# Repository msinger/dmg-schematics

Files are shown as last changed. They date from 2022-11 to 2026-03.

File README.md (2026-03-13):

Game Boy DMG-CPU Schematics
===========================

Contains reverse engineered schematics of the Game Boy DMG-CPU B chip, including the SM83 CPU core, as well as
VLSI layouts and parsable netlists.

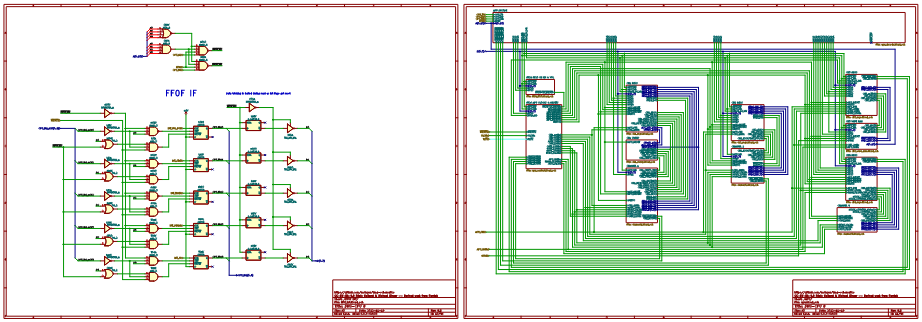
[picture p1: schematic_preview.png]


Originally, the DMG-CPU B schematics in this repository were derived from the schematics in
[furrtek/DMG-CPU-Inside](https://github.com/furrtek/DMG-CPU-Inside) (CC-BY-SA 4.0 Furrtek). They contain a lot of fixes
that were never applied to DMG-CPU-Inside.

PDF Export
----------

Most recent PDF exports can be found in the
[release](https://github.com/msinger/dmg-schematics/releases) section on github.

Files in this repo
------------------

| File(s) | Description |
| --- | --- |
| ./dmg\_cpu\_b/\* | KiCad project with schematics of the DMG-CPU B chip. |
| ./sm83/\* | KiCad project with schematics of the SM83 CPU core. |
| ./dmg\_cpu\_b/overlay/dmg-cpu-b\_overlay.svg | Modified version of Furrtek's overlay for the chip's die shot. |
| ./dmg\_cells/dmg-cpu.jelib | Electric VLSI cell library containing layouts of the standard cells used in the chip. |
| ./sm83\_cells/sm83.jelib | Electric VLSI cell library containing the layout of the complete SM83 CPU core. |
| ./netlist/\* | Text files containing all cells and wires, and their connections and coordinates. |

Overlay SVG
-----------

The overlay SVG image contains the contours of the cells in the die shot and highlights all the wires
connecting the cells. Also, the cells are labeled with the same names they have in the schematics.

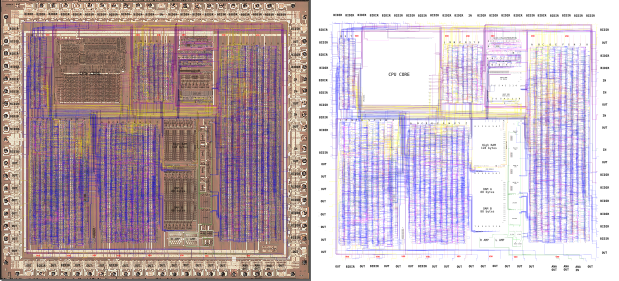
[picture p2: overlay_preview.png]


We took the overlay from Furrtek and modified it to keep it in sync with the fixed schematics.

To open the overlay with an SVG viewer/editor (like Inkscape) you need to download the die shots and place
them into the same directory where the overlay file is.
The die shots (`nintendo_dmg-cpu-b_mcmaster_mz_mit20x.jpg` and `nintendo_dmg-cpu-b_mcmaster_s1-1_mit20x.jpg`)
can be downloaded from [here](https://siliconpr0n.org/map/nintendo/dmg-cpu-b/single/).

Electric VLSI Library
---------------------

The [Electric VLSI](https://www.staticfreesoft.com/) libraries contain layouts for the standard cells used
in the chip as well as the complete SM83 CPU core.

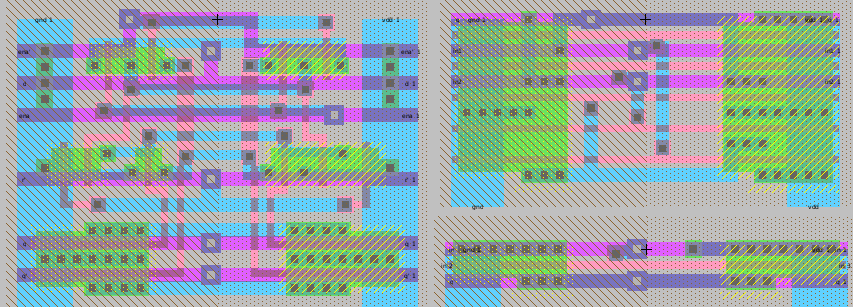
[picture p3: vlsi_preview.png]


Screenshots of these layouts can be seen in the cell reference documentations:
[dmg\_cells](http://iceboy.a-singer.de/doc/dmg_cells.html),
[sm83\_cells](http://iceboy.a-singer.de/doc/sm83_cells.html)

Netlist
-------

The files in the netlist folder contain definitions for all cells and wires of the chip.
They can be parsed by the [nlconv](https://github.com/msinger/nlconv/) tool. This tool is
currently capable of converting the netlists into the following products:
 * HTML file with colors and links that make the netlists more readable.
 * PNG images that are used for the overlays on the Leaflet maps of the chip:
   [dmg\_cpu\_b\_map](http://iceboy.a-singer.de/dmg_cpu_b_map/) and
   [sm83\_map](http://iceboy.a-singer.de/sm83_map/).
 * JavaScript code that is used by the same Leaflet maps for allowing the user to click on and select cells and wires,
   to get more information about them.
 * SystemVerilog code for simulating the chip: [dmg-sim](https://github.com/msinger/dmg-sim/)

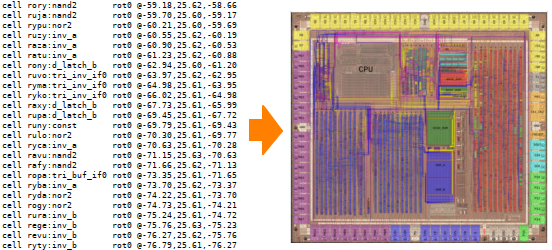
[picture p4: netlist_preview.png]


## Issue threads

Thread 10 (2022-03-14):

JOY: SIN IO-pad pull-up enable is wrong

msinger, 2022-03-14:
On joypad sheet, the pull-up enable input of the SIN IO-pad should be connected to net FF60_D0, not GND. This is also wrong in Furrtek's schematic.

Closed 2022-03-16.

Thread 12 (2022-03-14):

CLOCK: AGUT pins swapped

msinger, 2022-03-14:
On clock sheet, inputs 1&2 of AGUT are swapped. Makes no difference though, since both are inputs to or gate part of this OA cell. Also wrong in Furrtek's schematic.

Closed 2022-03-16.

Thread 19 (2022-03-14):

JOY: Block with AXYN, ADYR, ... belongs to another sheet

msinger, 2022-03-14:
The block in the top right corner of the joypad sheet should be moved to another sheet. I'm not sure where it fits best however. Maybe CPU sheet. The comment is wrong. This block is used for pre-charging the data bus at the beginning of each memory cycle. It causes non-existent bits in address range 0xFE00-0xFFFF to always be read as 0xFF.

There is also a bug that got transferred over from Furrtek's schematics: The signal FROM_CPU is wrong. This should be T1~{T2}.

Closed 2022-03-16.

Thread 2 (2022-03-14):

INT: Replace PESU with VCC

msinger, 2022-03-14:
On the interrupt sheet, PESU should be replaced with direct connection to VCC.

Closed 2022-03-16.

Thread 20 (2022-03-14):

DMA: Inputs of LAVY are swapped

msinger, 2022-03-14:
On DMA sheet, the inputs of AND gate LAVY are swapped.

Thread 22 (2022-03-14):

DMA: Input 1 of LYXE is wrong

msinger, 2022-03-14:
On DMA sheet, input 1 of LYXE (see also #21) is wrongly connected to LORU. It should be connected to LAVY instead. This bug got carried over from Furrtek's schematic.

Closed 2022-03-16.

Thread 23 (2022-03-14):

DMA: Latch enable inputs are inverted

msinger, 2022-03-14:
The D_LATCH_A enable inputs on the DMA sheet all need to be inverted.

Closed 2022-03-16.

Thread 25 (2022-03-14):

DMA: Input 2 of NAXY is wrong

msinger, 2022-03-14:
On DMA sheet, input 2 of NAXY is wrongly connected to Q output of LUVY. It should be connected to the CLK input of LUVY, which is DMA_PHI. This was also wrong in Furrtek's schematics.

Closed 2022-03-16.

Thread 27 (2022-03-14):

SER: SCK IO-pad is not connected correctly

msinger, 2022-03-14:
On serial sheet, the SCK IO pad is not correctly connected:

* First, it should be IOBUF_C, not _B. SCK is the only IO of that type. I don't know what's the difference, though,
* DRV_LOW and DRV_HIGH inputs are swapped. NOR gate KUJO should be connected to the NMOS driver (DRV_LOW) and NAND gate KEXU should be connected to the PMOS driver (DRV_HIGH).
* The pull-up resistor should be enabled by signal SCK_DIR, instead of GND.

rgalland, 2022-03-16:
Well done for working this one out.

Closed 2022-03-16.

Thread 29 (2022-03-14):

SYS_DEC: Reset input pad should be labeled ~RESET

msinger, 2022-03-14:
On the SYS_DECODE sheet, the reset input pad should be labeled with a bar on top, because the reset pin is active low.

On page 19 of [Nintendo's Game Boy Programming Manual](http://index-of.es/Varios-2/Game%20Boy%20Programming%20Manual.pdf) this pin is labeled ~RESET. Also in the [1996 Sharp Microcontroller Data Book](https://archive.org/details/1996_Sharp_Microcomputer_Data_Book/page/n147/mode/2up) on page 148 of the PDF (141 is written on the page itself), the SM83xx family has the reset pin labeled ~RESET.

There are other non official sources that label it ~RST, like in [Jeff Frohwein's GameBoy Schematic](https://www.devrs.com/gb/files/gameboy1.gif), but I think we should go with the official writing style.

Closed 2022-03-16.

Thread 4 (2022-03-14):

JOY: P10_IN, ..., P13_IN are inverted

msinger, 2022-03-14:
On joypad sheet, the signals P10_IN, P11_IN, P12_IN and P13_IN should have a bar on top, because they are inverted.

msinger, 2022-03-16:
No we can't label the pins active low like ~P10. They are not labeled active low in any documents and this would contradict how they are used in software:
Reading bit 0-3 in FF00 yields the non-inverted state of inputs P10-P13. And writing bits 4-5 to 0 causes outputs P14&P15 to be driven to GND. So they shouldn't be labeled as active low.

But since the input buffer of all IO pads are inverting, the internal signal P10_IN should be ~P10_IN instead to reflect that inversion.

Closed 2022-03-16.

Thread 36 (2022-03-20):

EXT_ADDR: Label ~EXT_ADDR_EN placed wrong

msinger, 2022-03-20:
On EXT_ADDR_BUSES sheet, the label ~EXT_ADDR_EN, which was NET01 in Furrtek's schematics, should come from TOVA, not RYCA.

msinger, 2022-03-20:
Also, there should be no connection between SYZU and NEFE. SYZU gets its enable input from RYCA. NEFU and the others get it from TOVA.

Closed 2022-03-20.

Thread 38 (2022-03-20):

EXT_ADDR: Many wrong DMA_A0 labels

msinger, 2022-03-20:
On EXT_ADDR_BUSES sheet, there are many MUX select inputs labeled DMA_A0, which should have another index other than 0.

rgalland, 2022-03-20:
Oops, A bit tired here.

Closed 2022-03-20.

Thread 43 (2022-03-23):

DUCE conencted to FERY

rgalland, 2022-03-23:
Hi @msinger, can you understand why FERY is not connected to FF18?

msinger, 2022-03-23:
Yes, I can. In Furrtek's schematics there is a connection, because it's hard to follow the wires here on the die shot. He just didn't see it correctly. Took me a long time too, to find this. I made two images in issue furrtek/DMG-CPU-Inside#62 already, that illustrate the problem.

msinger, 2022-03-23:
So, this means you can also remove the outgoing hierarchical label DUCE on the APU decode sheet, I think.

Closed 2022-03-24.

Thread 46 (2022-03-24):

APU_DEC: Inputs of some gates are swapped

msinger, 2022-03-24:
On APU decode sheet, the inputs of following gates are swapped:
DYVA, CAXE, EDAF, DECO, DUJA, COVY, DUTU, DARA, DOZA, EMOR, EKEZ

I compared it with the die shot. Furrtek also made a few mistakes here.

msinger, 2022-03-24:
Just noticed, the inputs of the NAND_4 gates are also scrambled up. I say we leave them like that for now. :)

rgalland, 2022-03-24:
I'll leave a note on the schematics about the NAND inputs.

Closed 2022-03-24.

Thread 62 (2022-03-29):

APU CH2: Swapped inputs

msinger, 2022-03-29:
On APU CH2 sheet, inputs of GUFY are swapped.

Btw., you left something copy&pasted from CH1 below this sheet (out of bounds). Probably used it for comparing the similar circuits.

Closed 2022-03-29.

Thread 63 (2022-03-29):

APU CH3 REGS: Missing FEVO and wrong connections to GUXE

msinger, 2022-03-29:
On APU CH3 register sheet, FEVO is missing. Also there are wrong connections carried over from Furrtek.

* Q output of GUXE should be connected to FEVO's input and nowhere else. Then output of FEVO goes into GEKO, like it is drawn in Furrtek's schematics.
* ~Q output of GUXE should go into FUVO input 1. The label ~CH3_AMP_EN (aka. ~FF1A_D7) should stay at the ~Q output.

msinger, 2022-03-29:
Also look at #64 before making changes. It's in the same area.

rgalland, 2022-03-29:
Also fixed BUTA on CH2 as output was not connected to ~Q. I also renamed all labels to CHx_FDIS instead of CHx_FEN as it makes more sense.

Closed 2022-03-29.

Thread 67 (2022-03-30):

APU CH4 REGS: ~FF23_D6 label is missing

msinger, 2022-03-30:
On APU channel 4 register sheet, the label ~FF23_D6 is missing on CUNY's ~Q output. In Furrtek's schematic this label is placed at CEPY's output, which is wrong. CEPY only connects to COTE. You have correctly identified DODA input 3 as ~FF23_D6. I wasn't aware of that bug before, thanks.

msinger, 2022-03-30:
Also DYRY shouldn't be connected to CEPY. DYRY input 1 is FF23_D6, not ~FF23_D6. This is wrong in Furrtek's schematic.

Closed 2022-03-31.

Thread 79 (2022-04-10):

PPU STAT: Wrong output of WUSA used

msinger, 2022-04-10:
On PPU STAT sheet, WUSA has the wrong output connected. It should use Q instead of ~Q.

rgalland, 2022-04-10:
Well spotted. I always end up getting it wrong when flipping these latches. In this case, I didn't even need to as WUSA could have sat above XYMU without crossing signals. This will be fixed in next commit.

Closed 2022-04-10.

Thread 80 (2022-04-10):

PPU STAT: FF45 latches are in random order

msinger, 2022-04-10:
On PPU STAT sheet, the latches of register FF45 are in wrong order. They actually have the reversed random order than in Furrtek's schematic. From top to bottom (7 to 0), they should be named:
RAHA
VEVO
VAFA
SOTA
SALO
SEDY
VUCE
SYRY

The tri-states and XORs are in correct order.

Closed 2022-04-10.

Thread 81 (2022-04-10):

Redrawing FULL ADD symbol

rgalland, 2022-04-10:
Do you mind if we draw the FULL ADD symbol to have from top to bottom :
- A, B, CIN on the left
- and COUT and SUM on the right?

This will prevent a lot of lines crossing over. At the moment, only the SWEEP sheet is affected but it look as I always try to have the MSB at the top.

msinger, 2022-04-10:
Let's do it. It's good to have everything ordered the same way. And if changing the pin order is making everything more readable, then that's good to.

Closed 2022-04-10.

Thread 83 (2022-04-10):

PPU LCD: SACU is an OR

msinger, 2022-04-10:
On PPU LCD sheet, SACU should be an OR gate, not a NOR. Is also wrong in Furrtek's schematics.

Closed 2022-04-10.

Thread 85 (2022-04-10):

PPU: Missing file

msinger, 2022-04-10:
Forgot to add background.kicad_sch to repo.

rgalland, 2022-04-10:
It's not ready yet but I can add it in case it messes up the Kicad project on your side.

msinger, 2022-04-11:
Ok, thanks. I thought you may have forgotten it. FYI.: KiCad loads the project and a warning about the missing file pops up, but the other sheets can still be viewed/edited normally.

Closed 2022-04-10.

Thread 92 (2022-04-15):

PPU WIN: ~RESET of RYFA and RENE is not connected

msinger, 2022-04-15:
On PPU window detection sheet, the ~RESET inputs of RYFA and RENE are not connected to any driver. They should be connected to MODE3 (XYMU.~Q).

Closed 2022-04-15.

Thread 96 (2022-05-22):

PPU VRAM_IFC: TEGU input 2 is wrong

msinger, 2022-05-22:
On VRAM interface sheet, input 2 of TEGU should not be connected to WRITE_EN (AFAS). It is connected to WRITE (FROM_CPU3). This is also wrong in Furrtek's schematics: furrtek/DMG-CPU-Inside#48

rgalland, 2022-05-23:
Well done. I thought that didn't make sense.

Closed 2022-05-23.

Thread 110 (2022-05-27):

PPU PX_MUX: Wrong connections between MEXA/LOZO/MABY/LYLE and LEDO/LARU/LYKY/LOPU

msinger, 2022-05-27:
On pixel mux sheet, MEXA should be connected to input 1 of LYKY and LOPU, not LARU. LOZO should be connected to input 1 of LEDO and LARU, not LYKY. MABY should be connected to input 2 of LOPU and LARU, not LYKY. LYLE should be connected to input 2 of LEDO and LYKE, not LARU.

Closed 2022-05-27.

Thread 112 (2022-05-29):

PPU DECODE: BOTA should be NAND

msinger, 2022-05-29:
On PPU decode & video control sheet, BOTA should be a NAND, not a NOR. This is also wrong in Furrtek's schematics.

msinger, 2022-05-29:
Well, I'm confused. The symbol is already NAND, but the label is NOR.

Closed 2022-05-30.

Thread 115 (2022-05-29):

PPU OAM: GND and +5V swapped

msinger, 2022-05-29:
On OAM sheet, WYDU and GECA should be connected to +5V, WUWE and GEFY should be connected to GND.

Closed 2022-05-30.

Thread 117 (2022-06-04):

CPU: Wrong OSC_STABLE input

msinger, 2022-06-04:
On CPU sheet, the OSC_STABLE (T15) input of the CPU is not 16Hz. It is output of TABA.

rgalland, 2022-06-05:
Well spotted.

msinger, 2022-06-05:
You forgot updating the ports of the CPU sheet symbol on the top sheet. 16Hz is still there and RESET_RELEASE is not connected.

Also I hate to nag, but I don't think RESET_RELEASE is a good name. Because for the CPU this not only gets signaled when the reset is released. It also happens after waking up from STOP instruction. STOP instruction causes OSC_ENABLE to swicth off. When the CPU gets the WAKE signal, then it rises OSC_ENABLE again, then TABU again takes some time until it signals stable oscillator back to the CPU. When in STOP mode, the CPU doesn't get reset, otherwise it wouldn't continue running after the STOP instruction. That's why I think RESET_RELEASE doesn't quite fit. Most of the other parts of the chip are reset during STOP mode, so for them it would be true that the reset is released at that point. But this signal goes to the CPU specifically.

rgalland, 2022-06-05:
Yes, I wouldn't mind giving it a more meaningful name but could not come with anything. Did you want to call OSC_STABLE? Is this a name you got from the Z80 documentation? Also do you what the relation is between CLK_ENA and OSC_ENA. It looks like CLK_ENA can only go high when reset stops otherwise TUBO would prevent the 16Hz signal to be seen by ASOL.

msinger, 2022-06-05:
No, I think I came up with OSC_STABLE on my own after experimenting a lot with the simulation. You are correct. The CPU must not pull CLK_ENA high before OSC_STABLE is high. Otherwise some of the reset signals will not go away. I already documented somewhat about this on my page http://iceboy.a-singer.de/doc/dmg_cpu_connections.html in row T11.
I concluded that the CPU has to do the following and implemented that in my simulation:
1. On reset, initially keep CLK_ENA low. OSC_ENA can be high immediately.
2. When OSC_STABLE rises, CPU drives CLK_ENA high. Now CPU starts actually running, because now it has all clocks.

When CPU encounters a STOP instruction it drives OSC_ENA and CLK_ENA low. When WAKE goes high, then it repeats from step 1. (OSC_ENA=high; wait for OSC_STABLE; CLK_ENA=high)

When CPU encounters a HALT instruction it drives CLK_ENA low, but keeps OSC_ENA high of course. Now the rest of the system is still clocked, but the CPU misses most of its clocks and won't continue executing. An interrupt will cause the CPU to drive CLK_ENA high again. It doesn't use WAKE, because WAKE is only for waking up if there is no clock at all. When in HALT the CPU still has some clock.

Yes, I would call it OSC_STABLE.

rgalland, 2022-06-06:
Thank you for the explanation, it makes a lot of sense. I'll have to check my VHDL code but I think that's how I implemented STOP and HALT instructions.
The signal will be renamed in the next commit to OSC_STABLE but I can leave the issue open until then.

Closed 2022-06-08.

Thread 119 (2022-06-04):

PPU DECODE: XECY is DR-latch

msinger, 2022-06-04:
On video decode sheet, XECY is a DR_LATCH, not D_LATCH_A. Its data input comes from D7, not XEBE. But its /RESET input comes from XEBE. Enable input should be WARU, not XUCA. XUCA is connected to its /ENA input, so XUCA is just a COMP CLOCK. This is also wrong in Furrtek's schematic. It is correct that Q output is in use and /Q is NC.

Closed 2022-06-05.

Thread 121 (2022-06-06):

SPRITE Y COMP: TOBU and VONU wrong connections

msinger, 2022-06-06:
On sprite Y comparator sheet, the clock of TOBU and VONU should come from TAVA (CLK5), not CLK4. Also, Q output of TOBU should be used. /Q is NC. Both of this is also wrong in Furrtek's schematic.

Closed 2022-06-08.

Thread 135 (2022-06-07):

Bus labels ending in underscore

msinger, 2022-06-07:
For some reason you added an underscore at the end of most sprite related bus labels (like SAVE_SPRITE_X_[0..9]).
Although, this may look good for the individual wires coming out of those buses (SAVE_SPRITE_X_0), it is inconsistent with other buses (like OAM_PARSE_A[2..7]).
More bothering to me is that when we translate this schematics one-to-one to Verilog or VHDL, we would end up with ugly vector or array names that have this underscore at the end.

rgalland, 2022-06-09:
True, this is a good point.

rgalland, 2022-06-09:
Changed other buses too.

msinger, 2022-06-09:
SPRITE_X_ and SPRITE_ON_ still have _

Closed 2022-06-10.

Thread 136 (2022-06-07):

SPRITE X MATCH TOP: Wrong data input for VEZO

msinger, 2022-06-07:
On sprite X match top sheet, VEZO should get constant +5V into its data input, not GND.

Closed 2022-06-09.

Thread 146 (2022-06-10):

IO pin names

msinger, 2022-06-10:
I would like to have the IO pins labeled the same as they are in the official Programming Manual on page 20: https://archive.org/details/GameBoyProgManVer1.1/page/n19/mode/2up

Right now, some are missing the bar on top (MCS, MWR, MOE). In the manual, MOE is labeled /MRD. This makes it consistent with the cartridge bus. On the PCB of the Game Boy Pocket, the test point on this trace is also labeled MRD. (http://iceboy.a-singer.de/db/mgb_iceboy_1/pcb_front.jpg)
Also in the Game Boy Color Service Manual, the pin names seem to match the ones from the Programming Manual: https://gamesx.com/wiki/lib/exe/fetch.php?media=schematics:gameboy_color_service_manual.pdf

You labeled /CS as /RAM_CS. I think it would make sense to add a comment next to it that says "RAM chip select" and then also next to A15 that says "ROM chip select".

As an exception, I think we should stick with PHI. I don't think it is a good idea to add Greek letters to KiCad.

I don't know how to best name the oscillator IO pins. We can leave it as it is or name it CK1_CK2, or just CK? I haven't figured out which one (CK1 or CK2) is output and which is input. In non-official documentation, they are mostly labeled XI and XO. I might have to measure it on a Game Boy Pocket. They are also labeled on its PCB.

I also think it may be good to have a comment next to each IO pin, that contains the pin number (or numbers in case of OSC).

When we start changing the SVG overlay later, we should not forget to name all the pins the same there.

Maybe we can add IO pads for GND and VDD also.

What do you think?

rgalland, 2022-06-11:
These are all good comments. I'll stat with renaming the pins according to the manual and adding notes as you suggested.

I can only imagine that CK1 is XO and CK2 is XO but I will need to check. In anycase, we can use CK1 and CK2 and add notes again.

Yes, it definitely make sense to have the GND and 5V pins to show that they do come from somewhere.

Let's leave this ticket open for now and perhaps use it to list all of the tasks to be done and then move to individual issues if they are big tasks. The overlay will be a big one.

msinger, 2022-06-11:
@Gekkio drew a pinout of the chip: https://github.com/Gekkio/gb-ctr/blob/master/images/DMG-CPU-pinout.pdf
According to this, pin 74 is CK1. I know from my experiments that pin 74 is the clock input and pin 73 is the output.
This means CK1 is XI and CK2 is XO. I don't know what you guessed in your comment, because you accidentally wrote XO twice. :grin:

What I also found while looking through his stuff, you can put nets with different names on one single bus now in KiCad, like he did here: https://github.com/Gekkio/gb-schematics/blob/main/MGB-xCPU/schematic/MGB-xCPU.pdf

rgalland, 2022-07-02:
I'm about o commit changes. Can you please check naming is suitable?

msinger, 2022-07-03:
Looks good

Closed 2022-07-07.

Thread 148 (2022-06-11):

*_PHI signals

msinger, 2022-06-11:
Since the PHI IO pin itself is inverting the signal that goes through it, the net CPU_PHI1 should be called /CPU_PHI1 to be logically correct. And as a consequence, all other *_PHI signals that are derived from that need to be inverted too.

I think we should find another name for CPU_PHI2, because it looks different than the clock that comes out of the PHI pin. PHI is symmetric, CPU_PHI2 is not. I find if someone sees a signal called *_PHI in the schematics, they should be allowed to safely assume that it is related to what comes out of the PHI pin. One could argue, well, if the name ends with a number 2, then it is a different PHI, but this argument falls apart when looking at /DMA_PHI2, which is derived from DMA_PHI, which comes from /DMA_PHI, which comes from the symmetric CPU_PHI1.

rgalland, 2022-07-02:
This is a fair point. I'll invert the signals for now.

rgalland, 2022-07-02:
How about CPU_T4. This is quite a good name as we know that each CPU cycle takes 4 clock cycles. I'll commit now so you can have a look.

msinger, 2022-07-03:
Yes, I think this makes sense, because CPU_T4 is high during the 4th tick.

Still two things left here:
CPU_PHI1 can now be called just CPU_PHI, without the 1, because CPU_PHI2 is gone.
You forgot to remove the inversion from DMA_PHI and APU_PHI after inverting CPU_PHI1.

rgalland, 2022-07-08:
I fixed phi2 and at the same time reordered the sheets + export a pdf. Please let me know what you think.

msinger, 2022-07-08:
Yes, very good. I'm finally happy with this.

Closed 2022-07-08.

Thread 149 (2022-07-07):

Overlay update

rgalland, 2022-07-07:
It is now time to add the overlay to the project and include several gates not present in the original schematics.

First items I can thing of adding are but not limited to:
- [ ] HRAM
- [ ] OAM
- [ ] Wave RAM

msinger, 2022-07-07:
Can we clean up a bit first? I would like to export a PDF and link it in the README.md so that people can open the schematic without the need for installing KiCad. I suspect the wave diagrams that are placed outside of frame to mess up a printout of the PDF. The pages can shrink because of that. Can we move them to another sheet?
I think it would make sense to have those diagrams outside of the schematic. We could make a documentation folder and put HTML documents in there that contain the diagrams. The wavedrom website states that the rendering engine can be embedded in HTML. It is java script. This way, we can store the source of the diagram and do not have to commit any image files. What do you think?

msinger, 2022-07-08:
I printed it out. It seems to work with the diagram data outside of frame. I was afraid that this text would be hidden in the PDF and mess up the scaling of the sheets when being printed. But the printout looks good. Even on A4, the font is big enough to be still readable. Only thing that is a bit unfortunate is that the green and red background colors of the boxes are making the yellow font of the labels unreadable. At least when printed in color. I haven't tried how it looks in black&white. I don't know what to do there, I like your idea of knowing where the IO pins are and which sheets have sub sheets. Maybe it works when we make the color much lighter?

Yes, we don't need the comments about the mistakes anymore.

msinger, 2022-07-08:
I just added the overlay file. I remember I made minor changes when I created the web browser map with it. I had to move some texts into the "labels" layer. They have been on the wrong layer and thus didn't show up on the map. But I didn't change any wires or cells or texts. Those should all be original.

Can you try if you can successfully open it with Inkscape when you place the two die shot files in the same directory where the overlay is in the repository? I added a .gitignore for them, so they don't get accidentally added.

The first file is the brownish die shot that Furrtek used:
https://siliconpr0n.org/map/nintendo/dmg-cpu-b/single/nintendo_dmg-cpu-b_mz_mit20x.jpg
The second one is this grayish/blueish one:
https://siliconpr0n.org/map/nintendo/dmg-cpu-b/single/nintendo_dmg-cpu-b_s1-1_mit20x.jpg

rgalland, 2022-07-10:
Inkscape was complaining for some reason as it could not find link to the first image but it working now.

msinger, 2022-07-10:
Oh no, I know why. My file has an underscore between "cpu" and "b". The file on siliconpr0n now has a dash/minus sign between them. They must have changed that at some point after I downloaded the file; or maybe I downloaded it from somewhere else back then. We should change that to a dash. What have you done to fix that?

rgalland, 2022-07-10:
I did a quick copy and paste in the overlay using the actual file name. I will soon commit the first cells added à round the Hram so that you can have look. I generated the cell names with your program.

Obtenir Outlook pour Android<https://aka.ms/AAb9ysg>
________________________________
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

msinger, 2022-07-10:
Looks good. Did you figure out which tool he used to draw the wires, or did you just copy one of the small orange pieces?
Also, is there a reason for naming the bottom two cells something with Bxxx instead of Axxx? There is also a misplaced or mislabeled cell in the top left "R" column called SETY. I was hoping we could fix this and make columns consistently starting with the same letter. Maybe there were some other too that I don't remember.

rgalland, 2022-07-10:
Yes, I wasn't thinking straight when giving the names. Yes, it should have been consistent so now I'm changing them to Axxx. I changed SETY and SAHA as well which was only a couple of cells up from SETY to ROSU and RONU.

rgalland, 2022-07-10:
I only copied and pasted the orange wires. I will need to figure out how to draw the lines properly later on.

rgalland, 2022-07-10:
Do you have any idea of a more relevant name for BUKE? It is almost like a data latch signal. What do you think?

msinger, 2022-07-10:
I don't know about BUKE. When naming the pins of the CPU symbol, I named it LATCH_CLK, because I was thinking it is the only clock like signal that does not have a complementary counterpart, like the other eight clock inputs of the CPU. But I wasn't thinking far enough, because latches also need an inverse. So I don't know what it is used for really. It flips at the same time as LAVO when there is a read operation going on. So LAVO latches the data that comes in from external data bus. Maybe the CPU also latches their data lines at the same moment. So I would be fine with that if you call it something with DATA_LATCH, like you suggested already.

rgalland, 2022-09-08:
@msinger , can you have a look at the boot rom buffer I created and let me know if it matches what you can see. There is a weird transistor that pulls up the input when it is not selected, otherwise, it inverts the rom bit and buffers it 4 times. It might make more sense to have the whole 8 bits instead of just one and have it as 1 symbol.

msinger, 2022-09-09:
The buffer you created... Do you mean "ZERY?" (/BOOT_CS)? You could route that /BOOT_CS signal into the /OE input. Or do you want to make OE high-active? But then we should be consistent and only draw the first ZERY inverter, like we do with the flip-flops that have complementary clock inputs. I thought maybe we could mention these hidden inverters for the flip-flops in comments next to the flip-flops.

This is what I see:
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

Yes, the one transistor that pulls the ROM bit high is weird. But I don't know the upper part of the ROM. Maybe the internal data line needs to be pre-charged with a 1. Maybe the ROM mask only contains NMOS transistors and is not capable to pull the data line high. This way, it is all more compact. When output gets enabled (ZERY=1) then the data line keeps its high state due to the capacitance of the wire. Only when there is an NMOS placed in the matrix above that is enabled by the selected addresses, the data line gets pulled low. But this is just a guess.

I don't understand what you mean in the last sentence. I feel I miss some context. :)

Do you have an idea what those SPARE cells are, that I wrote about in my last mail?

Again, you don't have to take care of the issues I post, if you want to spend time on your other projects. It's fine. :)

msinger, 2022-09-09:
This should be equivalent, I think:
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

rgalland, 2022-09-10:
Yes, the equivalent circuit is ok. Is it alright if I let you update the cmos_cells project? Have you also decoded the IO buffers for the HRAM, WAVERAM and OAM? In fact the WAVERAM IO buffer is different to the other 2.

msinger, 2022-09-10:
Yes, you're right. The inverter needs a defined state when the ROM is not accessed. That is also a reason for having this transistor.

I haven't noticed that you have already added something to the cmos_cells project. It should be fine if we only draw the schematic for one bit there. I would just call the data input and output Dn and Qn for example. I think the schematics are better to understand with a single 8-bit memory. But of course we have to change the address inputs to row and col selectors. I can update it, yes.

Do you want to have CS and ~CS on the symbol? I think this could be confusing, because there are actual memory chips with multiple chip select inputs, that all must be enabled for the chip to be active. But it is fine if not all are enabled at the same time, the chip is just disabled then. In our case, both inputs must be switched synchronously. If they are not, then it will either only drive high or only low, depending which CS is enabled. It's an illegal state, like for the flip flops with CLK and ~CLK. Do you know what I mean?

I haven't looked into the other memories in detail. But I don't think, the WAVE RAM IO buffer is much different. I think they just attach the outside data lines a bit differently because it has separate input and output, right?

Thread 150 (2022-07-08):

RUNY

rgalland, 2022-07-08:
I realised that RUNY is still in the schematics as an inverter. I'll pull the inputs of TAHY to SEDU to 5V.

msinger, 2022-07-08:
Silly me, I can just check it myself. :)

Closed 2022-09-08.

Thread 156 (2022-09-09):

Cells starting with wrong letters

msinger, 2022-09-09:
Some cells do still have names that don't fit into their column/row:

Only in overlay (clock complement):
- [x] JUZO needs to start with H

In schematic and in overlay:
- [x] TOMA needs to start with S
- [x] WEXY needs to start with V
(The new ones next to HRAM:)
- [x] BOFO and BABA need to start with A

Closed 2022-09-18.

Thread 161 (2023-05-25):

MODE2 wire is mislabeled as MODE1

tclemens, 2023-05-25:
It's source is `OAM_PARSING && !DMA_RUN`. It's also a component of `STAT[1]` which should only be set in modes 2 and 3.

msinger, 2023-05-25:
Thank you, I think you are right. Seems like we have overlooked this. If it raises bit 1 of the MODE[1:0] field in the STAT register, then it must be high during MODE2, not MODE1. I will check simulation results once more just to make sure, and then fix it.

msinger, 2023-05-25:
Hi @rgalland, thanks, I'm already done. Just about to push. :)

rgalland, 2023-05-25:
@msinger , man! you were fast.

msinger, 2023-05-25:
Let's hope I didn't miss something.

msinger, 2023-05-25:
Changing INT_VBL_BUF to INT_VBL would clean up FF0F INT (page 10). This was bothering me for a while that this is the only interrupt that hat a _BUF in its name.

msinger, 2023-05-25:
Oh, careful. :)
You mean, INT_HBL to MODE0.

rgalland, 2023-05-25:
Yes, that's what I meant.

Closed 2023-05-25.

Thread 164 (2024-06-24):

Fuse repos

ogamespec, 2024-06-24:
Suggestion to merge all DMG research repositories into one common repository.
From the current list of repositories it is not very clear what each repository is for, as they are all used in some way for DMG research and DMG circuit reconstruction.

msinger, 2024-06-26:
Hm, I was thinking for a while now. I wouldn't want to throw everything together. I still have nightmares from 2018 when I was forced to use CVS at work. One huge garbage shit pile repository.

It would make sense to move the cell documentation to the schematics repo, which already contains the cell layouts.
And also to move the Wide-Boy doc to the wideboy repo. But I wouldn't want to merge the dmg schematics with the Wide-Boy stuff for example. The gbreveng repo is kind of a dumpster of experiments and it also contains html docs. I think the dmg schematics repo should only contain the final product (schematics, layout, docs) for people that are just interested in that.

I can also try to add better README.md files to all repos and also give them a better short description. I don't know what a github project would offer, if that helps in organizing the repos. What do you think?

Can you tell me what the actual thing was that may have frustrated you in your search? Was it to find the repo that contains the html files of the cell documentation for creating the issue with the missing piece of metal?

ogamespec, 2024-06-26:
In general, I agree, WideBoy can be made separately and not mixed in a heap.

> Can you tell me what the actual thing was that may have frustrated you in your search?
Well, here's the easy part. The first thing I would like to know is where is the PPU, where is the APU (I mean standard cell domains).
I would also like to have the pinout of the chip at hand.
Also on the `map` I would like to see the name of the interconnects so I can match the pdf schematic with what I see on the `map`.
The cell description is on the website for some reason, but the pdf schematic is on GitHub. The `map` is also on the site and there is no way to look at the topology without a browser.

I guess it's subjective :)

ogamespec, 2024-06-26:
It's also not very clear where the "landing page" is. Where is the entrance to the "portal" so to speak? :)

ogamespec, 2024-06-27:
I think I found the landing page:

https://github.com/msinger/dmg-schematics/blob/master/README.md

msinger, 2024-06-27:
The landing page is supposed to be the [index page](http://iceboy.a-singer.de) of my website. But it was originally only about my FPGA implementation. Now everything else was added there. I'm not good at this. Yes, a good documentation would have an overview of the chip first maybe.

I don't know how I can do the net names on the map yet, but I'd like to have that too.

I thougt having a browser map would make it more accessible to everyone, because it just works. Before that we had the overlay SVG from Furrtek that you needed to align with the die shot in Inkscape. I did't like that, it was laggy all the time. I like the approach of having the actual information in text form from where it can be transformed. If you want to look at the huge PNG files locally without a browser, you can do that. You can use the [nlconv](http://github.com/msinger/nlconv) tool to convert the netlists to PNGs and then open them in Gimp or something similar that can handle huge images (16k x 16k pixels). I have actually documented the tool in the README.md file of that repository. If you can't get the Mono/C# stuff running, I can upload the images for you somewhere.

Yes, but the README.md in the dmg-schematics repo just describes the contents of that repo. Not the others. I don't think there is currently an overview for everything. It's so much to do. I always think I will make everything look good when I'm done with the real work. :)

ogamespec, 2024-06-27:
> If you want to look at the huge PNG files locally without a browser, you can do that.

Would it be possible to add something like this to the Release section on GitHub? It would be more convenient for me to study exactly the picture, right from my phone, instead of loading the site every time.
And if possible without a chip photo, there's no use for it. You can just solid background or even transparent, then PNG will not be big size.

msinger, 2024-06-27:
There is no chip photo in the background. The tool only generates the transparent overlays. I assume one PNG containing all four layers is convenient for you? Or do you want one PNG for each layer separately?

ogamespec, 2024-06-27:
It's better all in one, it's more convenient.

msinger, 2024-06-27:
I added the PNG to the [latest release](https://github.com/msinger/dmg-schematics/releases/tag/v0.6).

ogamespec, 2024-06-27:
> I added the PNG to the [latest release](https://github.com/msinger/dmg-schematics/releases/tag/v0.6).

Cool, thanks!

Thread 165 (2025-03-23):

Page 26 issues

ogamespec, 2025-03-23:
Hi, I found some inaccuracies on Page 26 and also added the signal names there. Please check :)

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

My annotated schematic can be found here:

https://github.com/emu-russia/dmgcpu/blob/main/wiki/soc/arb.md

msinger, 2025-03-23:
So you 'fixed' those two things:
 * There is a connection from `SALE`.`Q` to `SERE`.`IN2`
 * The TRI_INVs on the right hand side that drive the D[0..7] and MD[0..7] have the types:
    - INV_IF0, if they are in column R.
    - INV_IF1, if they are in column T.

Did I miss something?

So, I'm confused, because I see both things differently. I use the following trick to determine the polarity of the enable input of the TRI_INVs:

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

I took a look at `RAKU` and `TOKU`. Both of them have the dots on the same side, so they are IF1 in my opinion. Do you use a different approach in identifying those cells? Like I already listed it above, I noticed that you marked all TRI_INVs starting with an R as IF0, so maybe you switched GND and VCC in your mind when identifying those cells?

If you think about it, it makes no sense to have them enable on different logic levels. The ones that are driving D[0..7] all have the same signal on their enable input. If only some of the enable inputs were inverted, then there would be something driven onto D[0..7] continuously, and no other part of the SoC would be able to ever drive a whole byte onto D[0..7].

The `SALE`-`SERE` connection I also can't see:

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

I think there is a corner in the encircled area that connects from south to east. No straight connection from west to east.

Your signal names all make sense to me, btw. 😄

ogamespec, 2025-03-23:
SALE-SERE situation is actually my fault, sorry:

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

I'll double-check the tristates and write it up.

ogamespec, 2025-03-23:
on tristates. I distinguish them by the m1, which is shaped like a pistol:

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

My RAKU and TOKU (DMG CPU RevA):

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
(as you can see RAKU = notif0, TOKU = notif1)

it seems to be the revision of the CPU...

msinger, 2025-03-23:
I understand what you mean. But I don't know yet if it is true or false. Your pistol contains big and small vias. Sometimes the big via is at the tip, other times the small via is at the tip. This would mean that there are four different types of those TRI_INV cells, not just two. Because we would have:
 * Pistol to GND with big tip.
 * Pistol to GND with small tip.
 * Pistol from GND with big tip.
 * Pistol from GND with small tip.

I will search for the raw image you used for tracing those cells. Maybe you made a mistake there, or maybe we discovered new cell types. But as I argued before, those instances in this circuit here can't have opposite polarity, otherwise the data bus would be permanently blocked.

msinger, 2025-03-23:
Are all pictures you made from a rev A? Or did you open two different chips?

msinger, 2025-03-23:
I took pictures of RAKU, the left one is from your Cells_5_Fused.jpg that you took from the active/poly layer:

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

It points in the opposite direction than you have drawn it in your overlay layout. In Cells_5_Fused.jpg you can clearly see the three small vias. The big via is between metal, so it can't be seen anymore.

msinger, 2025-03-24:
On second glance, I think I interpreted the pistols different than you (made up by different metal parts), but it is still the opposite direction. 😆

ogamespec, 2025-03-24:
> Because we would have: ..

Can you show examples? (and have the gnd on the left).

> Are all pictures you made from a rev A? Or did you open two different chips?

I reconstruct the cell topology (poly) using RevB. And over RevA I mark the cells.
I use: https://siliconpr0n.org/map/nintendo/dmg-cpu-a/

I think you have the gnd on the right side in one place in the image, that's why it's confusing:

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

msinger, 2025-03-24:
No, I don't have examples for the four types. It was just an idea, trying to explain how they could still have the same polarity. There are most likely just two types. Since I understood your pistol in the wrong way, it wouldn't have been the tip of the pistol that was big or small, instead it would have been the trigger that was flipped around: Big hole at the front vs. small hole at the front. (Sorry, I don't know much about weapons, maybe my terminology is wrong. By 'trigger' I mean where you put your index finger through to fire the pistol.)

Considering your provided depiction of the pistol and looking at the rev A image that you used, I believe I still see the RAKU pistol point in the opposite direction that you:

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

ogamespec, 2025-03-24:
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

I double-checked, and it's my fault. I apologize, I think we can close Issue, but I'll be back :)

Closed 2025-03-24.

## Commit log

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2022-02-07 Add project with CMOS circuits
    for taking screenshots for cells documentation.
    [cmos_cells.kicad_pcb, cmos_cells.kicad_sch]
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2022-02-17 Errors fixed on int page.
    [dmg_cpu_b.kicad_sch, ff0f_int.kicad_sch]
2022-02-21 Add cell layout for inverter variants A & B
    [cmos_cells.kicad_pcb, cmos_cells.kicad_sch]
2022-02-23 Sheet 3 added - COUNT cells need adding
    [clocks_and_reset2.kicad_sch, cpu.kicad_sch, dmg_cpu_b.kicad_sch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]
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2022-02-27 Change MUXI and MUX symbols
    to better represent the actual function of the cell.
    The MUXI and MUX cells are not implemented by using NAND and NOR gates
    like the old symbol would hint to. The cells are implemented using
    transmission gates.
    [ff04_div.kicad_sch, ff05-07_timer.kicad_sch]
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2022-03-02 Sys decode page added - hierachical view needs to be reorganized
    [clocks_and_reset2.kicad_sch, cpu.kicad_sch, dmg_cpu_b.kicad_sch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]
2022-03-07 addr and data buses added and split on 2 sheets.
    [clocks_and_reset2.kicad_sch, cpu.kicad_sch, dmg_cpu_b.kicad_sch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]
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2022-03-08 Change TRI_INV datasheet links in schematics
    Régis, please just throw away this commit if you have merge issues.
    [ext_addr_buses.kicad_sch, ext_data_buses.kicad_sch, ff00_poyp.kicad_sch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]
2022-03-09 Add XOR and XNOR layouts
    and fix their schematics.
    [cmos_cells.kicad_pcb, cmos_cells.kicad_sch]
2022-03-11 Add layout and schematics for D-Latches, AO3 and SUPPLY cells
    [cmos_cells.kicad_pcb, cmos_cells.kicad_sch]
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2022-03-13 Add layout and schematic for tri-state buffer cell
    [cmos_cells.kicad_pcb, cmos_cells.kicad_sch]
2022-03-16 Crammed more gates in CH1 REGS page to include all read and writes to FF13-14.
    [apu.kicad_sch, ch1_regs.kicad_sch, dmg_cpu_b.kicad_sch]
2022-03-16 First lot of fixes based on issues found.
    [clocks_and_reset2.kicad_sch, dmg_cpu_b.kicad_sch, ff00_poyp.kicad_sch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]
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2022-03-20 Channel 2 + Channel 3 added. Channel 3 fits on 2 sheets.
    [apu.kicad_sch, apu_control.kicad_sch, apu_decode.kicad_sch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]
2022-03-21 fixes made following review
    [apu.kicad_sch, apu_control.kicad_sch, ch1_sweep.kicad_sch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]
2022-03-23 Fixes on Data bus page + APU CH4 regs page added.
    [apu.kicad_sch, ch3_regs.kicad_sch, ch4_regs.kicad_sch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]
2022-03-24 Fixes made from issues, channel 4 sheet aded and tidy up of hierarchical APU sheet. Small fixes done here and there when doing ERC.
    [apu.kicad_sch, apu_control.kicad_sch, apu_decode.kicad_sch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]
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2022-03-28 Fixes made based on raised issues. PPU decode page added as draft level.
    [apu.kicad_sch, apu_control.kicad_sch, apu_decode.kicad_sch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]
2022-03-29 Further fixes made based on raised issues.
    [apu.kicad_sch, ch1_regs.kicad_sch, ch2_regs.kicad_sch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]
2022-03-31 Fixes made based on raised issues (in APU sheets).
    [apu.kicad_sch, ch3_regs.kicad_sch, ch3_wave_ram.kicad_sch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]
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2022-04-10 Fixed based on raised issues in PPU region.
    [dmg_cpu_b.kicad_sch, ff41_stat.kicad_sch, lcd.kicad_sch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]
2022-04-10 Fixes and and rearranged schematics whereever possible to improve legibility.
    [ch1_sweep.kicad_sch, dmg_cpu_b.kicad_sch, ff41_stat.kicad_sch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]
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2022-05-01 Some mistakes found in APU sheets, notes added for clarity. Edit in PPU sheets following review.
    [background.kicad_sch, channel1.kicad_sch, channel4.kicad_sch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]
2022-05-03 VRAM interface sheet added but various edits in existing sheets. Notable merge of RESET, CLOCKS and FF04 DIV sheets
    [apu.kicad_sch, apu_control.kicad_sch, apu_decode.kicad_sch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]
2022-05-04 Error fixed on VRAM interface page - error flwoed down from original schematics.
    [clocks_and_reset2.kicad_sch, dmg_cpu_b.kicad_sch, ff0f_int.kicad_sch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]
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2022-05-07 OAM and sprite x priority sheets added. OAM sheet still needs some work on it.
    [clocks_and_reset.kicad_sch, clocks_and_reset2.kicad_sch, dmg_cpu_b.kicad_sch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]
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2022-05-12 more oam sheets added. Some are still work in progress.
    [apu.kicad_sch, apu_control.kicad_sch, dmg_cpu_b.kicad_sch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]
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2022-05-19 All sheets captured. Serious tidying is required in PPU section.
    [apu.kicad_sch, apu_control.kicad_sch, apu_decode.kicad_sch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]
2022-05-19 New sheet created to free up space on LCD and SCX/SCY sheets and joined common signals.
    [background.kicad_sch, bg_px_shifter.kicad_sch, bg_win_cycles.kicad_sch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]
2022-05-23 Fixes from raised github issues + tidy up of hierarchical sheets. WIP on WAVE RAM sheets.
    [apu.kicad_sch, apu_decode.kicad_sch, ch3_wave_ram.kicad_sch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]
2022-05-27 Fixes based on review. + various other edits.
    [bg_px_shifter.kicad_sch, bg_win_cycles.kicad_sch, ch3_wave_ram.kicad_sch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]
2022-05-30 Changes made based on review. PPU hierarchcal sheet work started.
    [bg_win_cycles.kicad_sch, dmg_cpu_b.kicad_sch, ff46_dma.kicad_sch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]
2022-06-02 PPU hierarchical page progress. Elements moved out of window sheet to be includes in BG and WIN cycles sheet
    [bg_px_shifter.kicad_sch, bg_win_cycles.kicad_sch, clocks_and_reset.kicad_sch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]
2022-06-02 All connections between sheet are complete. Can still do with a good tidy up.
    [apu.kicad_sch, apu_control.kicad_sch, background.kicad_sch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]
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2022-06-09 Elements from sptite control sheet moved to lcd sheet.
    [apu.kicad_sch, background.kicad_sch, bg_px_shifter.kicad_sch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]
2022-06-09 Quite a few fixes from review.
    [bg_px_shifter.kicad_sch, ch3_wave_ram.kicad_sch, clocks_and_reset.kicad_sch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]
2022-07-02 Issues addressed. Renaming and inverted signal names to make thing more consistent and meaningful.
    [apu.kicad_sch, apu_decode.kicad_sch, background.kicad_sch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]
2022-07-07 Fixed PHI signals.
    [apu.kicad_sch, bg_px_shifter.kicad_sch, ch1_regs.kicad_sch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]
2022-07-08 Fixed DMA phi2 signal. Notes tidied up, page order modified and draft pdf created for review.
    [apu.kicad_sch, apu_control.kicad_sch, apu_decode.kicad_sch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]
2022-07-08 Unnecessary comments removed. Data buffers moved to CPU page.
    [apu_control.kicad_sch, bg_px_shifter.kicad_sch, ch3_wave_ram.kicad_sch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]
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2022-09-01 Update - edits were done some time ago so cannot rcall what has been done.
    [ch3_wave_ram.kicad_sch, clocks_and_reset.kicad_sch, dmg_cpu_b.kicad_sch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]
2022-09-08 Slight schematics updates. Attempt at creating Boot ROM data buffer.
    [cmos_cells.kicad_sch, cpu.kicad_sch, dmg_cpu_b.kicad_sch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]
2022-09-10 Fix done based on github tickets #152 to #155
    [apu_control.kicad_sch, ch1_regs.kicad_sch, ch1_sweep.kicad_sch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]
2022-09-12 fixes issues #155 #158 and #159
    [ch3_wave_ram.kicad_sch, clocks_and_reset.kicad_sch, dmg_cpu_b.kicad_sch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]
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2022-09-18 Overlay fixes
    * Remove stray COMP CLOCK label near POLO
    * Remove stray COMP CLOCK label near left GND pad
    * Remove meaningless A and B labels from wires below column D at the right
    * Remove A, B, C labels on IO pads on right side
    * Rename row below BOOT ROM from F to Z, since the cells start with Z
    * Fix RD and WR from being labeled as OUT to BIDIR
    * Add IN and OUT label to analog pads
    * Add IN and OUT label to unbonded pads
    * Recolor RESET wire from purple/control to turquoise/reset
    * Recolor SCK.q wire from blue/data to magenta/clock
    * Recolor wire between CPU.T14 and CK1_CK2.~ena from magenta/clock to purple/control
    * Recolor SYCY.q wire from magenta/clock to purple/control
    * Recolor TULO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
2022-09-18 More overlay fixes
    * Rename TOMA to SABE
    * Fix wrong wiring described in #43
    * Mark XECY and XUVA as spare
    * Move labels on right side of CPU to "Labels" layer
    * Add redish tint to VDD rails
    * Recolor wires:
    RULO.q address -> control
    SUZE.q address -> control
    ROVE.q data -> control
    RELA.q data -> control
    ROCY.q data -> control
    REVO.q data -> control
    RYJE.q data -> control
    RUVY.q data -> control
    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
2022-09-18 Add pin numbers to IO pads in schematics
    [bg_win_cycles.kicad_sch, clocks_and_reset.kicad_sch, ext_addr_buses.kicad_sch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]
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2022-09-18 Fix some symbols
    * Fix some symbols that had gaps in their yellow background
    * Change D7-D0 ports on CPU and memories from tri-state to bidir
    * Fix some datasheet links
    [apu_control.kicad_sch, apu_decode.kicad_sch, background.kicad_sch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]
2022-09-18 Update cell names in WAVE RAM WIP area and fix swapped A2/A3
    [ch3_wave_ram.kicad_sch, dmg_cpu_b.kicad_sch]
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2022-10-11 Overlay fixes
    - Complete wire from COTA.q to WOVU.in
    - Fix existing wires around WAFA, WYXY, WEXE and WAZU
    - Add wire from ZORO.q to ZUFA.in2
    Recolor:
    - LYSA.q data:blue -> adr:yellow
    - LOXO.q data:blue -> ctl:purple
    - LYWE.q data:blue -> ctl:purple
    - LAGU.q data:blue -> ctl:purple
    - LEVO.q data:blue -> ctl:purple
    - LETY.q data:blue -> ctl:purple
    - LEJA.q data:blue -> ctl:purple
    - LESA.q data:blue -> ctl:purple
    - LUFE.q data:blue -> ctl:purple
    - LAMO.q data:blue -> ctl:purple
    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
2022-10-26 Add missing WLDRV_ENA input to high RAM
    [apu_control.kicad_sch, apu_decode.kicad_sch, background.kicad_sch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]
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2022-10-28 Fix CPU clocks inputs T4 & T5
    [cpu.kicad_sch]
2022-10-29 Add control logic for OAM RAMs (out of bounds for now)
    Also rename wires:
    * CPU_OAM_RD (BOTA) -> ~CPU_OAM_RD
    * OAM_RD (LEKO) -> CPU_VRAM_OAM_RD
    * ~OAM_OE (ZODO) -> ~OAM_RD
    [dmg_cpu_b.kicad_sch, oam.kicad_sch, ppu.kicad_sch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]
2022-10-31 Update the names of the two unbonded pads in schematics
    [cpu.kicad_sch, dmg_cpu_b.kicad_sch]
2022-11-02 Overlay: Fix color of a small part of wire BEDO
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2022-11-06 Fix OAI, MUX and MUXI pins
    [cmos_cells.kicad_sch]
2022-11-19 Input swaps and name changes
    - Inputs of LOKO swapped.
    - Inputs of ZUFA swapped.
    - Remove labels on P14 and P15.
    - Rename BOOT_EN to BOOT_SEL. BOOT_EN could be confused with the bit stored in the FF50 register.
    - Rename T1T2 to ~{TEST_RESET}. T1T2 is easily misunderstood to be high whenever T1 and T2 are high. It is actually low when T1 and T2 are high, but only during reset. The name ~{TEST_RESET} suggests that it is an active low reset signal that is only used for testing.
    - Rename CPU pins DATA_CLK_x to PHI_CLK_x.
    - Rename CPU pins INC_CLK_x to T4_CLK_x.
    - Rename CPU pin and wire MEM_RQ to MREQ. This is how it is labeled in Z80 documentation.
    - Rename FEXX-FFXX (and ~FEXX-FFXX) to {,~}FEX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
    [clocks_and_reset.kicad_sch, cpu.kicad_sch, dmg_cpu_b.kicad_sch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]
2022-11-19 Fix BOOT_ROM symbol
    [dmg_cpu_b.kicad_sch, sys_decode.kicad_sch]
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2022-11-23 Rename some nets
    - Rename FF04-FF07 to FF04_FF07
    - Rename ~FFOF_RD (with letter O) to ~FF0F_RD (with digit zero)
    - Rename ~FFOF_WR (with letter O) to ~FF0F_WR (with digit zero)
    [clocks_and_reset.kicad_sch, dmg_cpu_b.kicad_sch, ff05-07_timer.kicad_sch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]
2022-11-23 ~FF0F_RD is not connected to MUXE, NABE, RAKE, SULO nor SEME; it is ~FF0F_WR instead
    [ff0f_int.kicad_sch]
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2022-11-26 Swap inputs of URYS and MERY
    [ff01-02_serial.kicad_sch, ff05-07_timer.kicad_sch]
2022-11-26 Rename nets to fit naming scheme of other nets
    - Rename A00-07 to XX00_XX07
    - Rename A00-03 to FF00_FF03
    [dmg_cpu_b.kicad_sch, ff01-02_serial.kicad_sch, ff05-07_timer.kicad_sch]
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2022-11-27 Rename ATAL_INV to ADEH and add cell TYGU
    [apu.kicad_sch, apu_decode.kicad_sch, clocks_and_reset.kicad_sch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]
2022-12-04 Swapped inputs and renamed some nets and cells
    - Rename DETA_INV to DAXU
    - Rename EVYF_INV to DUSO
    - Rename DOGE_INV to CYHO
    - Rename DULU_INV to CAZO
    - Inputs of EMAX swapped
    - Inputs of DONA swapped
    - Inputs of DEWA swapped
    - Inputs of DUFE swapped
    - Inputs of GANY swapped
    - Inputs of EMOS swapped
    - Inputs of DATU swapped
    - Inputs of DURA swapped
    - Inputs of EGEN swapped
    - Rename CH1_BIT & CH2_BIT to CHn_PWM. It is not a bit. It is the actual "sound wave".
    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
    [apu.kicad_sch, apu_decode.kicad_sch, ch1_regs.kicad_sch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]
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2022-12-22 Rename some nets for consistency
    - Rename VOLL[2:0] and VOLR[2:0] to LVOLUME[2:0] and RVOLUME[2:0], to make them consistent with LMIXER[3:0] and RMIXER[3:0]
    - Rename VINL_EN and VINR_EN to L_VIN_EN and R_VIN_EN, to make them consistent with LMIXER and RMIXER and better readable
    - Rename ~FF24-26_RESET to ~FF24_FF25_FF26_RESET, so it doesn't have a minus sign in its name, which is not allowed when converting to HDL
    - Rename bit13_xnor_bit14 to LFSR_BIT13_EQ_BIT14
    - Rename FERO_Q to FF26_D4
    - Rename NET03 to FF26_D4_B
    - Rename WAVE_DAC_D[3:0] to CH3_OUT[3:0], makes them consistent with the outputs of the other three channels
    - Rename BAGE_INV to BAMU
    - Rename HOSO_INV to KUHU
    - Rename EPYX_INV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
    [apu.kicad_sch, apu_control.kicad_sch, ch1_regs.kicad_sch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]
2022-12-22 Swapped inputs
    - Inputs of BUGE swapped
    - Inputs of EGAD swapped
    - Inputs of BACU swapped
    - Inputs of BUSO swapped
    - Inputs of COPY swapped
    - Inputs of FURY swapped
    - Inputs of FASY swapped
    - Inputs 1 and 2 of DOKY swapped
    [ch2_regs.kicad_sch, ch3_regs.kicad_sch, ch3_wave_ram.kicad_sch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]
2022-12-22 Fix APU ch3 volume selection
    DOKY input 4 is now correctly connected to GOKA instead of GEMY.
    Fixes #160
    [ch3_wave_ram.kicad_sch]
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2023-01-04 Minor fixes in left half of PPU
    - Fix text "FF40 LDLC" to "FF40 LCDC"
    - Rename WIN_START_PULSE to just WIN_START
    - Rename LOMA_INV to LUNA
    - Rename RYVE_INV to PUPU
    - Rename PUCO_INV to ROZO
    - Rename XADO_INV to SUSE
    - Rename WANE_INV to VOZE
    - Rename BG_TILE_[7:0] to BG_TILE[7:0]
    - Rename SP0_D[7:0] to OBP0_D[7:0], because "SP" can be misunderstood as just SPrite, instead of Sprite Palette.
    - Rename SP1_D[7:0] to OBP1_D[7:0], because see previous
    - Rename SP0PX to OBJ0PX, because here "SP" means just SPrite, not Sprite Palette like before.
    - Rename SP1PX to OBJ1PX, because see previous
    - Remove labels ~CLK2 (2x)
    - Remove label TEVO
    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
    [bg_px_shifter.kicad_sch, bg_win_cycles.kicad_sch, dmg_cpu_b.kicad_sch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]
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2023-02-06 Minor fixes in right half of PPU
    [apu.kicad_sch, apu_control.kicad_sch, apu_decode.kicad_sch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]
2023-04-22 Update to KiCad 7 and fix page number of OAM Memory sheet
    Changed the page number of the OAM Memory sheet from 46 to 35, so that
    it comes directly after the OAM sheet (page 34).
    KiCad 7 now exports PDF with content tree for easier navigation.
    [apu.kicad_sch, apu_control.kicad_sch, apu_decode.kicad_sch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]
2023-05-25 Rename wire MODE1 -> MODE2
    Wire was mislabeled. Found by @tclemens.
    fixes #161
    [apu.kicad_sch, apu_control.kicad_sch, apu_decode.kicad_sch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]
2023-06-18 Add layout for IBUF_A and IBUF_B cells
    Also change cell type IBUF in schematics to:
    - T1, T2 and ~RST -> IBUF_A
    - ~NMI -> IBUF_B (has pull-up resistor)
    [apu.kicad_sch, apu_control.kicad_sch, apu_decode.kicad_sch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]
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2023-06-26 Rename INT_VBL* and INT_HBL wires
    As discussed in issue #161
    INT_VBL -> MODE1
    INT_VBL_BUF -> INT_VBL
    INT_HBL -> MODE0
    [apu.kicad_sch, apu_control.kicad_sch, apu_decode.kicad_sch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]
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2023-07-10 Fix schematics of NAND/AND cells
    [cmos_cells.kicad_sch]
2023-07-30 Boot ROM: Fix layout and add schematics
    [cmos_cells.kicad_sch]
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2024-05-29 Datasheet links for SM83 cells + fixes
    [sm83_cells.kicad_sch]
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2025-04-11 Give more meaningful names to cell types
    Before this commit, many of the cells types in the chip were named in a
    sloppy manner. The different inverter, latch and flip flop valiants were
    just suffixed with A, B, C, D, ... Those suffixes gave no information
    about the actual differences. They had to be looked up in the
    documentation. Now the names of cell types with different variants have
    changed:
    * Inverter types are named NOT_X1, NOT_X2, NOT_X3, ... The _Xn suffix
    reflects the drive strength of the cell. X1 is the drive strength of
    the weakest inverter, X2 is double the drive strength of the weakest
    inverter.
    * Flip flop types are named DFFR, DFFR_CC, DFFR_CC_Q. DFFR is a normal
    dat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
    [apu.kicad_sch, apu_control.kicad_sch, apu_decode.kicad_sch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]
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2025-10-22 SM83: Fix missing output in IDU0 schematic
    [sm83_cells.kicad_sch]
2025-10-23 SM83 Layout: Small fixes
    * Add two missing wires in top level.
    * Fix shape of top level A10 port.
    * Fix some port directions in IDU cells.
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2025-10-24 SM83 Layout: Fix some missing wires
2025-10-28 SM83 Layout: Fix missing wires and add exports
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2025-11-01 Fix missing annotation in IRQ_PRIO_BIT5 schematic
    [sm83_cells.kicad_sch]
2025-11-02 Fix DRLATCH schematic and symbol
    [sm83_cells.kicad_sch]
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2025-12-07 SM83: Update wire names of all reg bank inputs
    and rename DFFN_EE_Q_ALU_{TMP,SIGN}.
    [sm83_cells.kicad_sch]
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2025-12-25 SM83: Small IDU fixes
    * IDU_INC and IDU_DEC signals were swapped at muxer inputs.
    * ~{IDU_IN[0..15]} was missing ~{} in some places.
    [idu.kicad_sch, register_bank.kicad_sch, sm83.kicad_sch]
2026-02-17 DMG Cells: Add FULL_ADD layout and schematic
    Also update schematics for XOR, XNOR and HALF_ADD
    [dmg_cells.kicad_sch]
2026-02-19 DMG Cells: Fix DFFSR schematic
    [dmg_cells.kicad_sch]
2026-02-21 Fix PAD_BIDIR* cell schematics and symbols
    [apu.kicad_sch, apu_control.kicad_sch, apu_decode.kicad_sch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]
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2026-02-22 Netlist: Fix identical wire names in SV output
2026-02-24 Netlist: Minor wire name fixes
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2026-03-18 Fix Wave RAM column slelect
    [apu.kicad_sch, apu_control.kicad_sch, apu_decode.kicad_sch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]
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2026-04-06 Netlist: Fix audio output pin order
    * SO1 (ROUT) is pin 60
    * SO2 (LOUT) is pin 59
    DMG main board schematics out there are wrong.
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2026-08-21 Netlists: Account for overlap between DMG and SM83
    * Add attributes for subtracting the wire length that is traced in both
    netlists (DMG top level and SM83 CPU core).
    * Small wire fixes.
2026-09-07 SM83 Netlist: SV params for correcting net lengths
    Add some attributes for emitting SystemVerilog parameters to aid dmg-sim
    in calculating the correct net lengths for wires driven by the CPU.
